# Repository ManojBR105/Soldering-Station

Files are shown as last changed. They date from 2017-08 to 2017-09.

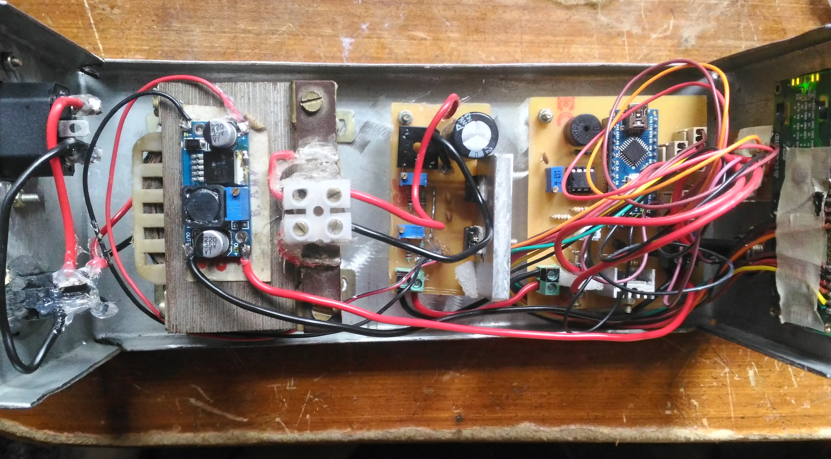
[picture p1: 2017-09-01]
FInished project/Top.jpg

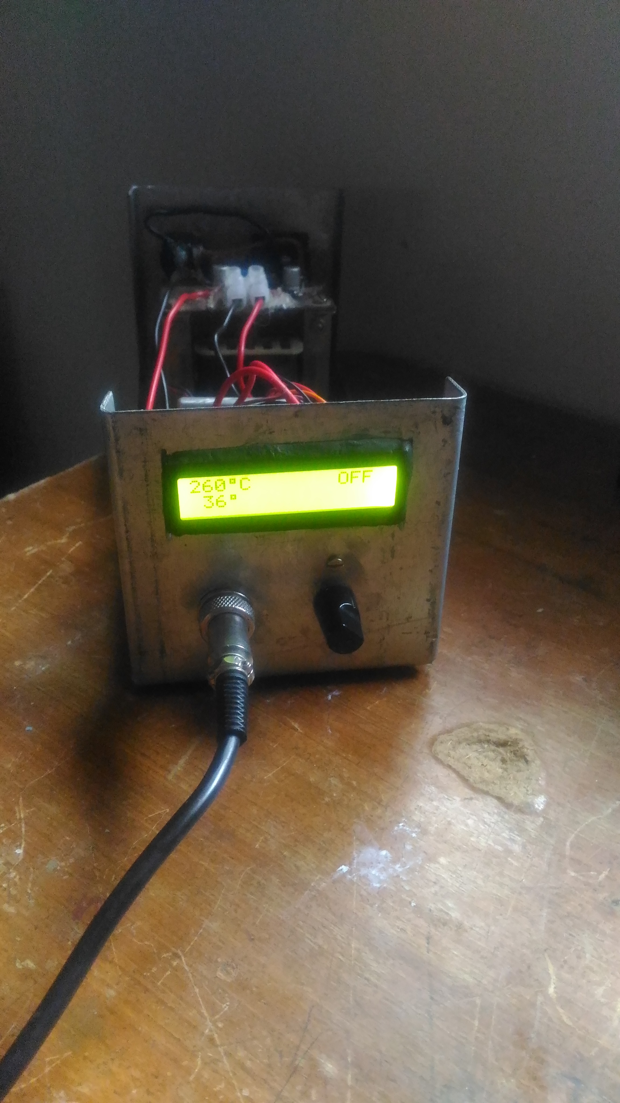
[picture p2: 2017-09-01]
FInished project/Front.jpg

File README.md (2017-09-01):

# Soldering-Station
Board and Schematics for Soldering station based on hakko 907 clone. 
Consider there is slight difference in schematic, the buzzer is connected to pin no.D13 of the arduino and the lcd pin connected to the D13th pin is connected to the D11th pin of the arduino. (please change this in the arduino code before uploading OR use the modified code in this repository).
In this layout LCD and Encoder are not on the PCB but are connected using Jumper Connectors which makes the assembling job easier when mounting this circuit into a Project case.
The eagle libraries that I have used for this schematic are also with this files copy them to your eagle library.
THANK YOU.

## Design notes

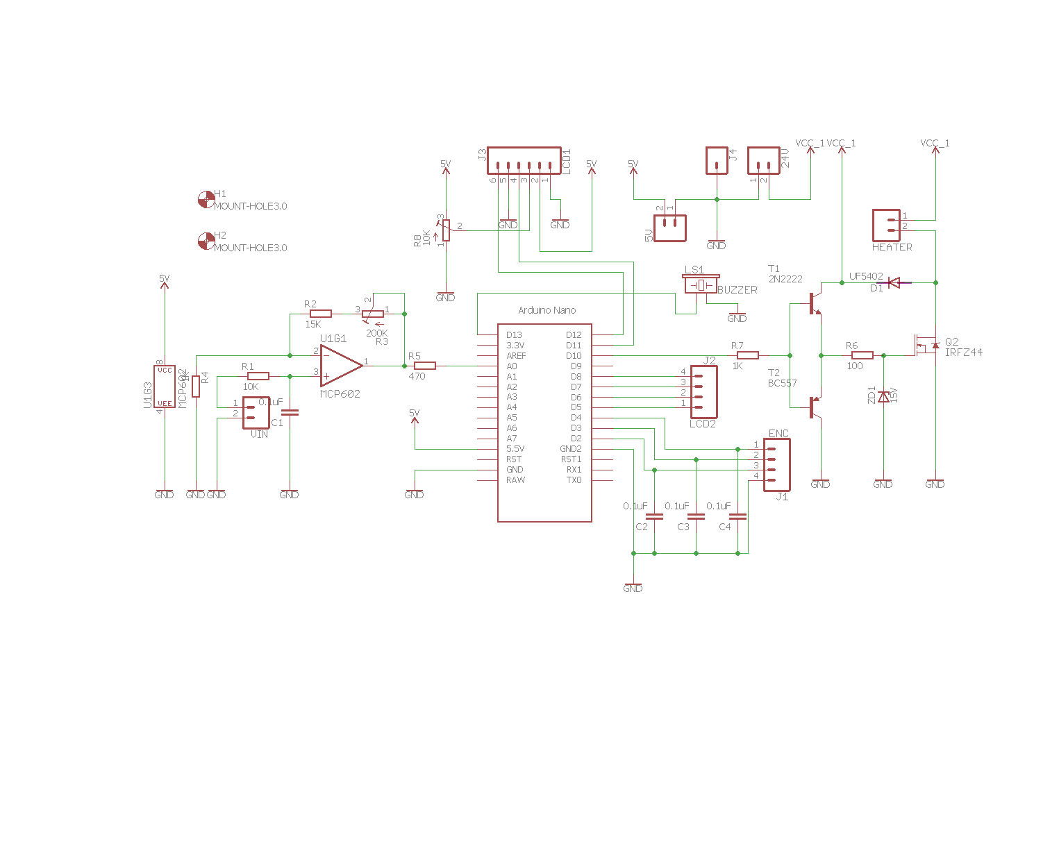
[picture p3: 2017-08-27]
EAGLE FILES/Soldering Station/Schematic.png

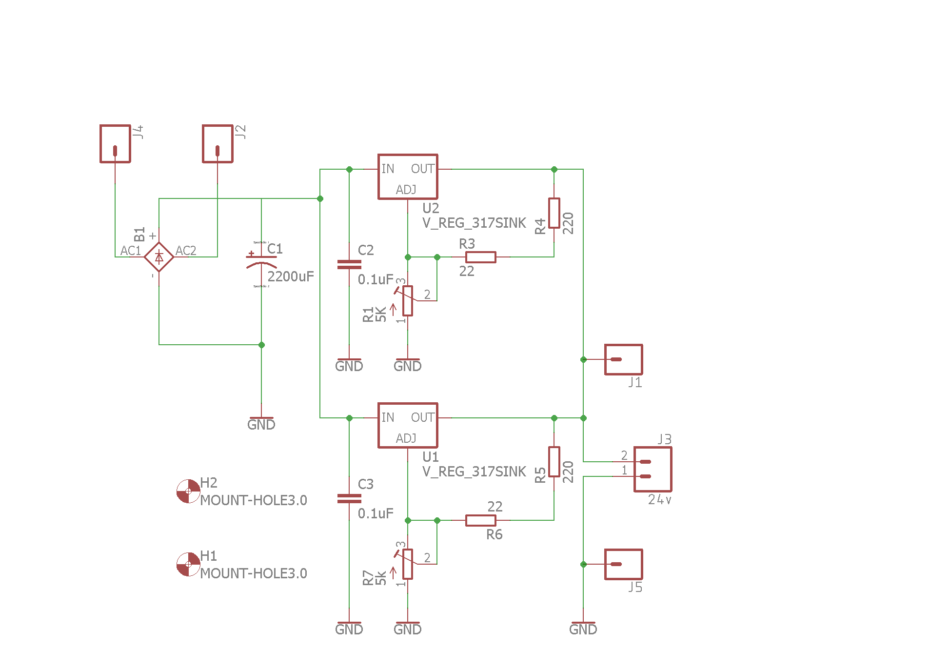
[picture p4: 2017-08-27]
EAGLE FILES/Power supply/Schematic.png

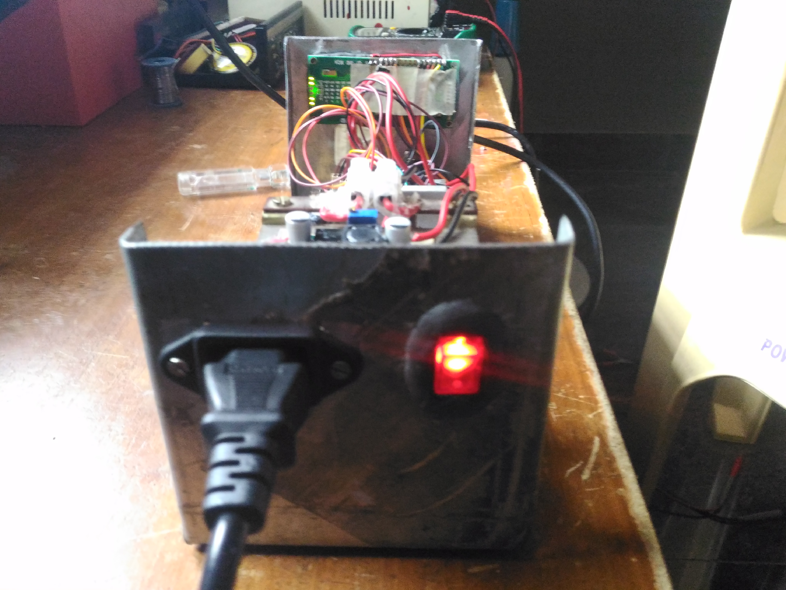
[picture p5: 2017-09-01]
FInished project/Back.jpg

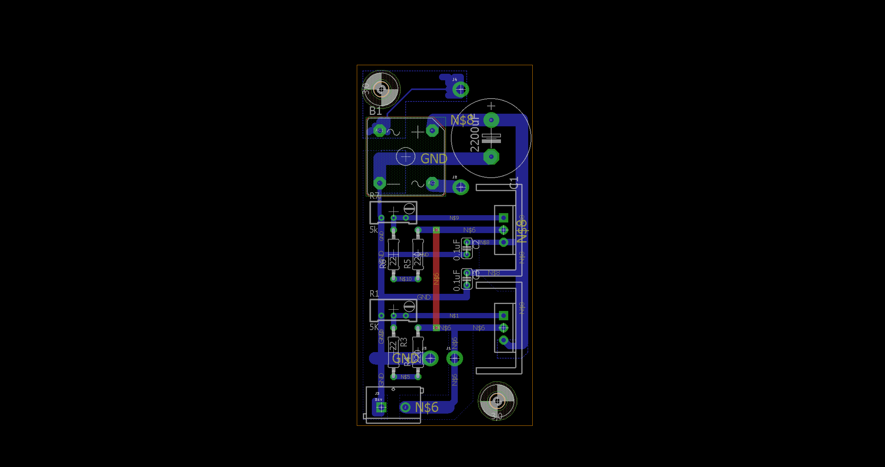
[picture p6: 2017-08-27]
EAGLE FILES/Power supply/Board.png

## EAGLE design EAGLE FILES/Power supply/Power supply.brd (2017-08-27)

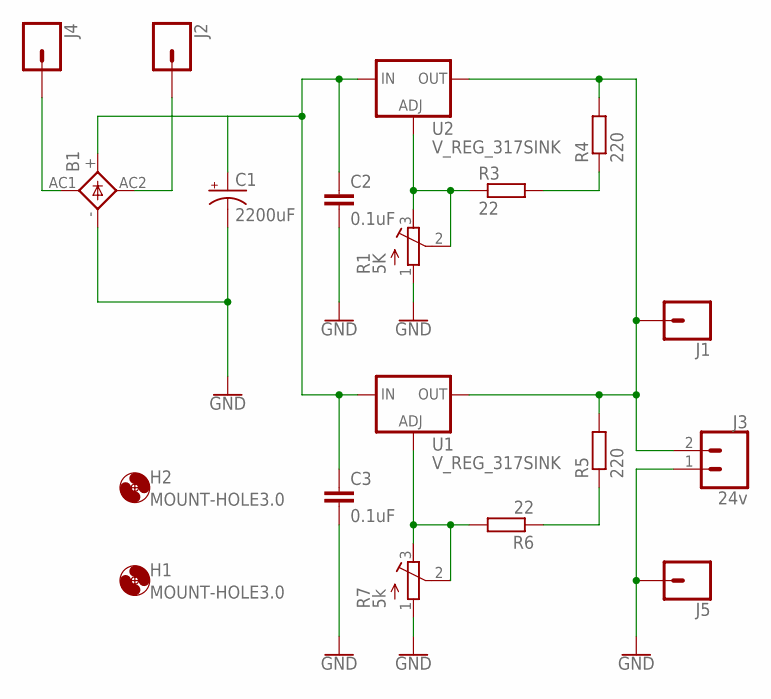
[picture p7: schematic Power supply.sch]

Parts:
B1: GBPC1
C1: 2200uF; E7,5-16
C2, C3: 0.1uF; C025-024X044
H1, H2: MOUNT-HOLE3.0; 3,0
J1, J2, J4, J5: CONN_01PTH_2MM; 1X01_2MM
J3: 24v; SCREWTERMINAL-5MM-2
R1: 5K; RTRIM64W
R3, R6: 22; 0207/10
R4, R5: 220; 0207/10
R7: 5k; RTRIM64W
U1, U2: V_REG_317SINK; TO220-ADJ

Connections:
GND: B1.-, C1.-, C2.2, C3.2, J3.1, J5.1, R1.1 (A), R7.1 (A)
unnamed: R1.2 (S), R1.3 (E), R3.1, U2.ADJ
unnamed: B1.AC1, J4.1
unnamed: B1.AC2, J2.1
unnamed: R3.2, R4.1
unnamed: J1.1, J3.2, R4.2, R5.2, U1.OUT, U2.OUT
unnamed: B1.+, C1.+, C2.1, C3.1, U1.IN, U2.IN
unnamed: R6.2, R7.2 (S), R7.3 (E), U1.ADJ
unnamed: R5.1, R6.1

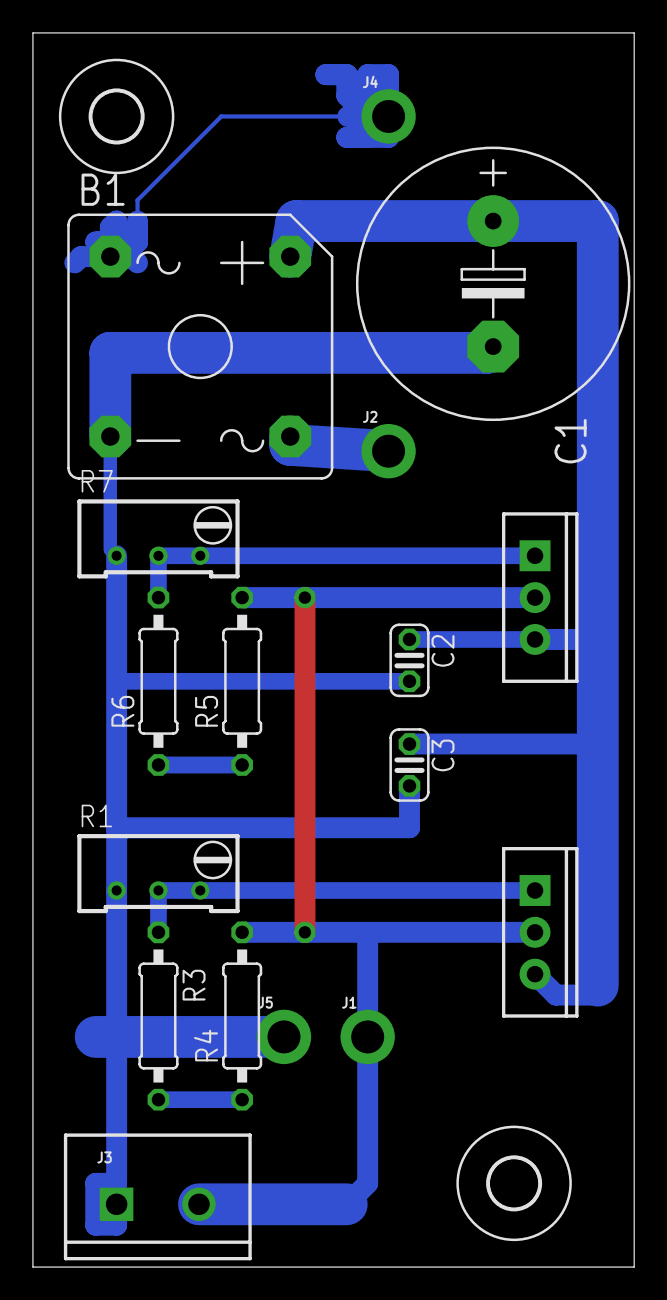
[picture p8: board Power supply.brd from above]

Board: 2 copper layers, 36.5 x 74.9 mm, 19 parts (0 on the bottom side), 9 nets.

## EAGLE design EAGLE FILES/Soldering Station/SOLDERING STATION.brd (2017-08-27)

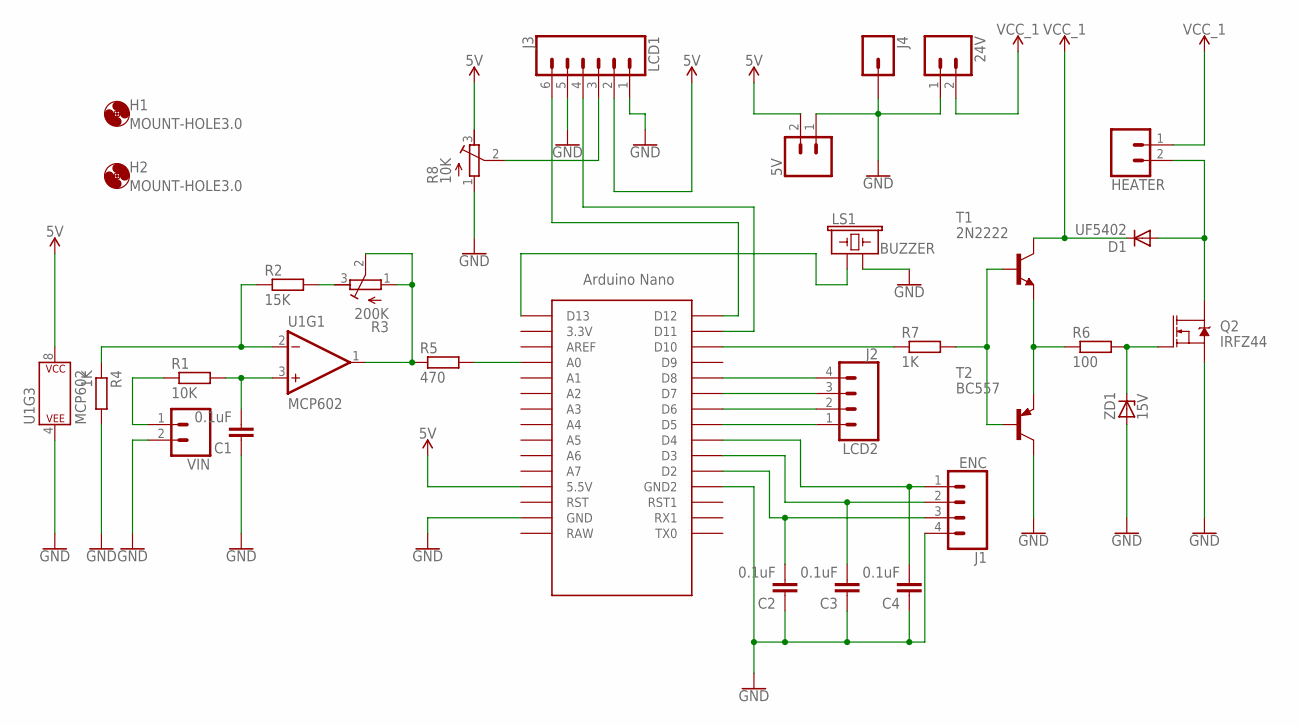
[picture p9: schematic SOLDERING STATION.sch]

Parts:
5V, 24V: CONN_025MM; SCREWTERMINAL-5MM-2
C1, C2, C3, C4: 0.1uF; C025-024X044
D1: UF5402; DO41-10
H1, H2: MOUNT-HOLE3.0; 3,0
HEATER: CONN_02PTH4; 1X02_XTRA_BIG
J1: ENC; 1X04_LONGPADS
J2: LCD2; 1X04_LONGPADS
J3: LCD1; 1X06_LONGPADS
J4: CONN_01PTH_2MM; 1X01_2MM
LS1: BUZZER; BUZZER-12MM-NS
Q2: IRFZ44; TO220V
R1: 10K; 0204/7
R2: 15K; 0204/7
R3: 200K; RTRIM64W
R4, R7: 1K; 0204/7
R5: 470; 0204/7
R6: 100; 0204/7
R8: 10K; RTRIM64W
T1: 2N2222; TO92-EBC-OVAL
T2: BC557; TO92
U1: MCP602; DIP08
U$1: NANO
VIN: CONN_02POLAR_LOCK; MOLEX-1X2_LOCK
ZD1: 15V; DO41Z10

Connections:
5V: 5V.2, J3.2, R8.3 (E), U1.8 (P$V+), U$1.5V (5.5V)
GND: 5V.1, 24V.1, C1.1, C2.1, C3.1, C4.1, J1.4, J3.1, J3.5, J4.1, LS1.- (2), Q2.3 (S), R4.2, R8.1 (A), T2.3 (C), U1.4 (P$V-), U$1.GND, U$1.GND1 (GND2), VIN.2, ZD1.A
unnamed: C1.2, R1.2, U1.3 (+IN)
unnamed: R2.1, R4.1, U1.2 (-IN)
unnamed: R1.1, VIN.1
unnamed: R2.2, R3.3 (E)
unnamed: R3.1 (A), R3.2 (S), R5.1, U1.1 (OUT)
unnamed: R5.2, U$1.A0
unnamed: R7.1, U$1.D10
unnamed: D1.A, HEATER.2, Q2.2 (D)
unnamed: C4.2, J1.1, U$1.D4
unnamed: R7.2, T1.B, T2.2 (B)
unnamed: R6.1, T1.E, T2.1 (E)
unnamed: Q2.1 (G), R6.2, ZD1.C
unnamed: C3.2, J1.2, U$1.D3
unnamed: C2.2, J1.3, U$1.D2
unnamed: J2.1, U$1.D5
unnamed: J2.2, U$1.D6
unnamed: J3.3, R8.2 (S)
unnamed: J2.3, U$1.D7
unnamed: J2.4, U$1.D8
unnamed: LS1.+ (1), U$1.D13
unnamed: J3.6, U$1.D12
unnamed: J3.4, U$1.D11
VCC_1: 24V.2, D1.C, HEATER.1, T1.C

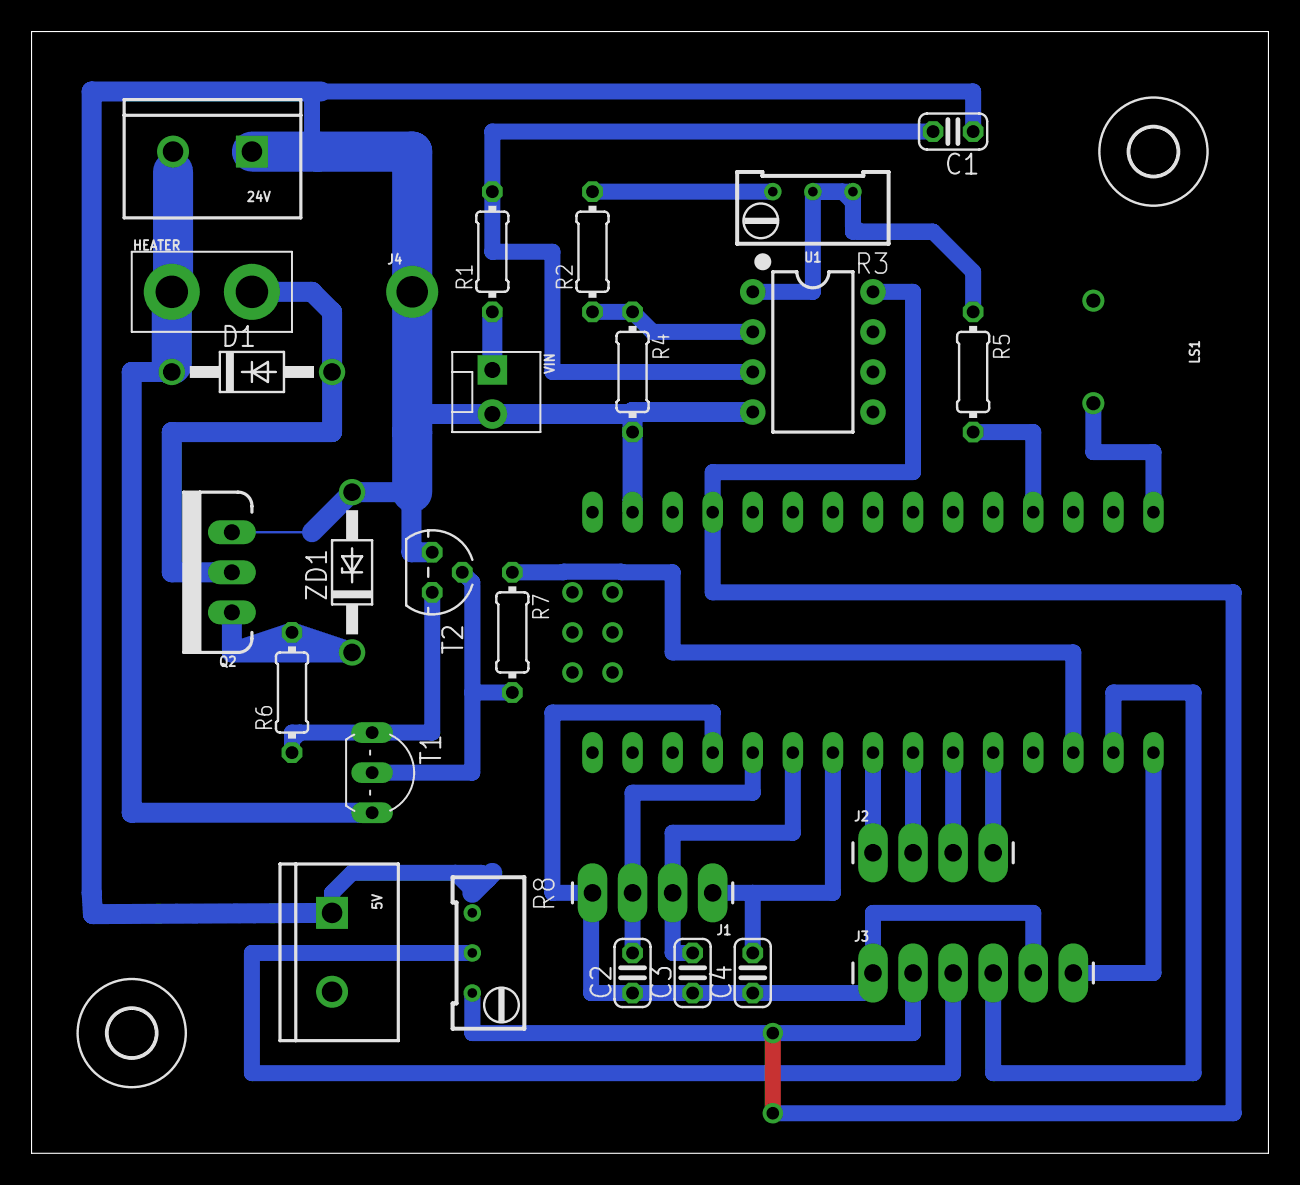
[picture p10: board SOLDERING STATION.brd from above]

Board: 2 copper layers, 78.4 x 71.1 mm, 30 parts (0 on the bottom side), 25 nets.

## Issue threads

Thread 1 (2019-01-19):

Soldering -Station / Modified.ino

giorgio-palma, 2019-01-19:
I've been trying to compile the sketch for a long time "
Modified.ino "(for display 1602) with the following arduino IDE version:
1.6.2
1.6.3
1.8.8 IDE
but the code gives me a compilation error.
You can help me??

giorgio-palma, 2019-01-25:
This is the error when compiling the "Modified.ino" code:
Arduino: 1.8.8 (Windows 8.1), Board: "Arduino Nano, ATmega328"

C:\Program Files (x86)\Arduino\arduino-builder -dump-prefs -logger=machine -hardware C:\Program Files (x86)\Arduino\hardware -hardware C:\Users\GIORGIOP\AppData\Local\Arduino15\packages -tools C:\Program Files (x86)\Arduino\tools-builder -tools C:\Program Files (x86)\Arduino\hardware\tools\avr -tools C:\Users\GIORGIOP\AppData\Local\Arduino15\packages -built-in-libraries C:\Program Files (x86)\Arduino\libraries -libraries C:\Users\GIORGIOP\Documents\Arduino\libraries -fqbn=arduino:avr:nano:cpu=atmega328 -ide-version=10808 -build-path C:\Users\GIORGIOP\AppData\Local\Temp\arduino_build_808351 -warnings=none -build-cache C:\Users\GIORGIOP\AppData\Local\Temp\arduino_cache_141 -prefs=build.warn_data_percentage=75 -prefs=runtime.tools.avrdude.path=C:\Users\GIORGIOP\AppData\Local\Arduino15\packages\arduino\tools\avrdude\6.0.1-arduino2 -prefs=runtime.tools.avrdude-6.0.1-arduino2.path=C:\Users\GIORGIOP\AppData\Local\Arduino15\packages\arduino\tools\avrdude\6.0.1-arduino2 -prefs=runtime.tools.avr-gcc.path=C:\Users\GIORGIOP\AppData\Local\Arduino15\packages\arduino\tools\avr-gcc\4.8.1-arduino2 -prefs=runtime.tools.avr-gcc-4.8.1-arduino2.path=C:\Users\GIORGIOP\AppData\Local\Arduino15\packages\arduino\tools\avr-gcc\4.8.1-arduino2 -verbose C:\Users\GIORGIOP\AppData\Local\Temp\arduino_modified_sketch_540121\sketch_jan25a.ino
C:\Program Files (x86)\Arduino\arduino-builder -compile -logger=machine -hardware C:\Program Files (x86)\Arduino\hardware -hardware C:\Users\GIORGIOP\AppData\Local\Arduino15\packages -tools C:\Program Files (x86)\Arduino\tools-builder -tools C:\Program Files (x86)\Arduino\hardware\tools\avr -tools C:\Users\GIORGIOP\AppData\Local\Arduino15\packages -built-in-libraries C:\Program Files (x86)\Arduino\libraries -libraries C:\Users\GIORGIOP\Documents\Arduino\libraries -fqbn=arduino:avr:nano:cpu=atmega328 -ide-version=10808 -build-path C:\Users\GIORGIOP\AppData\Local\Temp\arduino_build_808351 -warnings=none -build-cache C:\Users\GIORGIOP\AppData\Local\Temp\arduino_cache_141 -prefs=build.warn_data_percentage=75 -prefs=runtime.tools.avrdude.path=C:\Users\GIORGIOP\AppData\Local\Arduino15\packages\arduino\tools\avrdude\6.0.1-arduino2 -prefs=runtime.tools.avrdude-6.0.1-arduino2.path=C:\Users\GIORGIOP\AppData\Local\Arduino15\packages\arduino\tools\avrdude\6.0.1-arduino2 -prefs=runtime.tools.avr-gcc.path=C:\Users\GIORGIOP\AppData\Local\Arduino15\packages\arduino\tools\avr-gcc\4.8.1-arduino2 -prefs=runtime.tools.avr-gcc-4.8.1-arduino2.path=C:\Users\GIORGIOP\AppData\Local\Arduino15\packages\arduino\tools\avr-gcc\4.8.1-arduino2 -verbose C:\Users\GIORGIOP\AppData\Local\Temp\arduino_modified_sketch_540121\sketch_jan25a.ino
Using board 'nano' from platform in folder: C:\Users\GIORGIOP\AppData\Local\Arduino15\packages\arduino\hardware\avr\1.6.2
Using core 'arduino' from platform in folder: C:\Users\GIORGIOP\AppData\Local\Arduino15\packages\arduino\hardware\avr\1.6.2
WARNING: Category '' in library EEPROM is not valid. Setting to 'Uncategorized'
WARNING: Category '' in library SPI is not valid. Setting to 'Uncategorized'
WARNING: Category '' in library SoftwareSerial is not valid. Setting to 'Uncategorized'
WARNING: Category '' in library Wire is not valid. Setting to 'Uncategorized'
Warning: platform.txt from core 'Arduino AVR Boards' contains deprecated recipe.ar.pattern="{compiler.path}{compiler.ar.cmd}" {compiler.ar.flags} {compiler.ar.extra_flags} "{build.path}/{archive_file}" "{object_file}", automatically converted to recipe.ar.pattern="{compiler.path}{compiler.ar.cmd}" {compiler.ar.flags} {compiler.ar.extra_flags} "{archive_file_path}" "{object_file}". Consider upgrading this core.
Detecting libraries used...
"C:\\Users\\GIORGIOP\\AppData\\Local\\Arduino15\\packages\\arduino\\tools\\avr-gcc\\4.8.1-arduino2/bin/avr-g++" -c -g -Os -w -fno-exceptions -ffunction-sections -fdata-sections -fno-threadsafe-statics -w -x c++ -E -CC -mmcu=atmega328p -DF_CPU=16000000L -DARDUINO=10808 -DARDUINO_AVR_NANO -DARDUINO_ARCH_AVR "-IC:\\Users\\GIORGIOP\\AppData\\Local\\Arduino15\\packages\\arduino\\hardware\\avr\\1.6.2\\cores\\arduino" "-IC:\\Users\\GIORGIOP\\AppData\\Local\\Arduino15\\packages\\arduino\\hardware\\avr\\1.6.2\\variants\\eightanaloginputs" "C:\\Users\\GIORGIOP\\AppData\\Local\\Temp\\arduino_build_808351\\sketch\\sketch_jan25a.ino.cpp" -o nul
"C:\\Users\\GIORGIOP\\AppData\\Local\\Arduino15\\packages\\arduino\\tools\\avr-gcc\\4.8.1-arduino2/bin/avr-g++" -c -g -Os -w -fno-exceptions -ffunction-sections -fdata-sections -fno-threadsafe-statics -w -x c++ -E -CC -mmcu=atmega328p -DF_CPU=16000000L -DARDUINO=10808 -DARDUINO_AVR_NANO -DARDUINO_ARCH_AVR "-IC:\\Users\\GIORGIOP\\AppData\\Local\\Arduino15\\packages\\arduino\\hardware\\avr\\1.6.2\\cores\\arduino" "-IC:\\Users\\GIORGIOP\\AppData\\Local\\Arduino15\\packages\\arduino\\hardware\\avr\\1.6.2\\variants\\eightanaloginputs" "-IC:\\Program Files (x86)\\Arduino\\libraries\\LiquidCrystal\\src" "C:\\Users\\GIORGIOP\\AppData\\Local\\Temp\\arduino_build_808351\\sketch\\sketch_jan25a.ino.cpp" -o nul
"C:\\Users\\GIORGIOP\\AppData\\Local\\Arduino15\\packages\\arduino\\tools\\avr-gcc\\4.8.1-arduino2/bin/avr-g++" -c -g -Os -w -fno-exceptions -ffunction-sections -fdata-sections -fno-threadsafe-statics -w -x c++ -E -CC -mmcu=atmega328p -DF_CPU=16000000L -DARDUINO=10808 -DARDUINO_AVR_NANO -DARDUINO_ARCH_AVR "-IC:\\Users\\GIORGIOP\\AppData\\Local\\Arduino15\\packages\\arduino\\hardware\\avr\\1.6.2\\cores\\arduino" "-IC:\\Users\\GIORGIOP\\AppData\\Local\\Arduino15\\packages\\arduino\\hardware\\avr\\1.6.2\\variants\\eightanaloginputs" "-IC:\\Program Files (x86)\\Arduino\\libraries\\LiquidCrystal\\src" "-IC:\\Users\\GIORGIOP\\AppData\\Local\\Arduino15\\packages\\arduino\\hardware\\avr\\1.6.2\\libraries\\EEPROM" "C:\\Users\\GIORGIOP\\AppData\\Local\\Temp\\arduino_build_808351\\sketch\\sketch_jan25a.ino.cpp" -o nul
"C:\\Users\\GIORGIOP\\AppData\\Local\\Arduino15\\packages\\arduino\\tools\\avr-gcc\\4.8.1-arduino2/bin/avr-g++" -c -g -Os -w -fno-exceptions -ffunction-sections -fdata-sections -fno-threadsafe-statics -w -x c++ -E -CC -mmcu=atmega328p -DF_CPU=16000000L -DARDUINO=10808 -DARDUINO_AVR_NANO -DARDUINO_ARCH_AVR "-IC:\\Users\\GIORGIOP\\AppData\\Local\\Arduino15\\packages\\arduino\\hardware\\avr\\1.6.2\\cores\\arduino" "-IC:\\Users\\GIORGIOP\\AppData\\Local\\Arduino15\\packages\\arduino\\hardware\\avr\\1.6.2\\variants\\eightanaloginputs" "-IC:\\Program Files (x86)\\Arduino\\libraries\\LiquidCrystal\\src" "-IC:\\Users\\GIORGIOP\\AppData\\Local\\Arduino15\\packages\\arduino\\hardware\\avr\\1.6.2\\libraries\\EEPROM" "C:\\Program Files (x86)\\Arduino\\libraries\\LiquidCrystal\\src\\LiquidCrystal.cpp" -o nul
Generating function prototypes...
"C:\\Users\\GIORGIOP\\AppData\\Local\\Arduino15\\packages\\arduino\\tools\\avr-gcc\\4.8.1-arduino2/bin/avr-g++" -c -g -Os -w -fno-exceptions -ffunction-sections -fdata-sections -fno-threadsafe-statics -w -x c++ -E -CC -mmcu=atmega328p -DF_CPU=16000000L -DARDUINO=10808 -DARDUINO_AVR_NANO -DARDUINO_ARCH_AVR "-IC:\\Users\\GIORGIOP\\AppData\\Local\\Arduino15\\packages\\arduino\\hardware\\avr\\1.6.2\\cores\\arduino" "-IC:\\Users\\GIORGIOP\\AppData\\Local\\Arduino15\\packages\\arduino\\hardware\\avr\\1.6.2\\variants\\eightanaloginputs" "-IC:\\Program Files (x86)\\Arduino\\libraries\\LiquidCrystal\\src" "-IC:\\Users\\GIORGIOP\\AppData\\Local\\Arduino15\\packages\\arduino\\hardware\\avr\\1.6.2\\libraries\\EEPROM" "C:\\Users\\GIORGIOP\\AppData\\Local\\Temp\\arduino_build_808351\\sketch\\sketch_jan25a.ino.cpp" -o "C:\\Users\\GIORGIOP\\AppData\\Local\\Temp\\arduino_build_808351\\preproc\\ctags_target_for_gcc_minus_e.cpp"
"C:\\Program Files (x86)\\Arduino\\tools-builder\\ctags\\5.8-arduino11/ctags" -u --language-force=c++ -f - --c++-kinds=svpf --fields=KSTtzns --line-directives "C:\\Users\\GIORGIOP\\AppData\\Local\\Temp\\arduino_build_808351\\preproc\\ctags_target_for_gcc_minus_e.cpp"
Compiling sketch...
"C:\\Users\\GIORGIOP\\AppData\\Local\\Arduino15\\packages\\arduino\\tools\\avr-gcc\\4.8.1-arduino2/bin/avr-g++" -c -g -Os -w -fno-exceptions -ffunction-sections -fdata-sections -fno-threadsafe-statics -MMD -mmcu=atmega328p -DF_CPU=16000000L -DARDUINO=10808 -DARDUINO_AVR_NANO -DARDUINO_ARCH_AVR "-IC:\\Users\\GIORGIOP\\AppData\\Local\\Arduino15\\packages\\arduino\\hardware\\avr\\1.6.2\\cores\\arduino" "-IC:\\Users\\GIORGIOP\\AppData\\Local\\Arduino15\\packages\\arduino\\hardware\\avr\\1.6.2\\variants\\eightanaloginputs" "-IC:\\Program Files (x86)\\Arduino\\libraries\\LiquidCrystal\\src" "-IC:\\Users\\GIORGIOP\\AppData\\Local\\Arduino15\\packages\\arduino\\hardware\\avr\\1.6.2\\libraries\\EEPROM" "C:\\Users\\GIORGIOP\\AppData\\Local\\Temp\\arduino_build_808351\\sketch\\sketch_jan25a.ino.cpp" -o "C:\\Users\\GIORGIOP\\AppData\\Local\\Temp\\arduino_build_808351\\sketch\\sketch_jan25a.ino.cpp.o"
C:\Users\GIORGIOP\AppData\Local\Temp\arduino_modified_sketch_540121\sketch_jan25a.ino: In member function 'void DSPL::init()':

sketch_jan25a:553:36: error: invalid conversion from 'const byte* {aka const unsigned char*}' to 'uint8_t* {aka unsigned char*}' [-fpermissive]

   LiquidCrystal::createChar(1, cent);

                                    ^

In file included from C:\Users\GIORGIOP\AppData\Local\Temp\arduino_modified_sketch_540121\sketch_jan25a.ino:1:0:

C:\Program Files (x86)\Arduino\libraries\LiquidCrystal\src/LiquidCrystal.h:81:8: error:   initializing argument 2 of 'void LiquidCrystal::createChar(uint8_t, uint8_t*)' [-fpermissive]

   void createChar(uint8_t, uint8_t[]);

        ^

Using library LiquidCrystal at version 1.0.7 in folder: C:\Program Files (x86)\Arduino\libraries\LiquidCrystal
Using library EEPROM at version 2.0 in folder: C:\Users\GIORGIOP\AppData\Local\Arduino15\packages\arduino\hardware\avr\1.6.2\libraries\EEPROM
exit status 1
invalid conversion from 'const byte* {aka const unsigned char*}' to 'uint8_t* {aka unsigned char*}' [-fpermissive]

DeshmukhMalhar, 2019-01-26:
try changing
` const byte cent[8] `
to
` const uint8_t cent[8] `

giorgio-palma, 2019-01-26:
thank you so much now compile it out perfectly.
I had to change
"const byte cent[8]"
to
"uint8_t cent[8]"

Closed 2020-12-08.

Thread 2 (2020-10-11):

Current temp never changes

zhuhualong, 2020-10-11:
Hey Manoj,

I used your files (PCB and code) to make this sweet project.  Everything turned out great, but one little problem...  The Iron temp never changes from 25C.  I have tried two different irons and get the same.  If I click ON, it displays, "HEATING" and the percentage changes from 0% to 100% almost immediately and the it heats to almost 520C by my thermometer.

I am using your PCB.  I didn't have it printed, I made it myself.  The iron reads 50 Ohms when cold.  I have double checked all of the connections and the code "modified.ino" loads fine, no mods.

Do you have any suggestions on where to look?

I did notice one thing and it might mean nothing, when there is no iron connected, the temp reads at about 348C.

Thanks,
Michael

zhuhualong, 2020-10-12:
I did notice one thing while doing some testing with the multimeter, when I have the unit on, and connect the leads to the sensor pins, the temperature on the LCD displays correctly.  What do you think might be the problem?
I've double checked all of the solder joints for this part of the circuit and even swapped the MCP602 chip just to rule out a faulty IC.

Thanks
Michael

ManojBR105, 2020-12-08:
Hey Michael,
Sorry for replying late, I don't get notifications if you comment here. You can mail me at MakerBR555@gmail.com if you have any doubts.
I suggest you to test 2 things.
1. There is one red wire in the pcb, which is supposed to be a jumper wire that you have to solder from top externally. Make sure you did that.
2. Verify that your Soldering Iron has a thermocouple not thermistor as the temperature sensor.

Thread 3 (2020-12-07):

mistake in pcb file

samsam1202, 2020-12-07:
hi dear Manoj

I tried to build your project.

https://github.com/ManojBR105/Soldering-Station

I think there was a mistake in your eagle PCB board.

the 5-volt positive input in the PCB is grounded and did not connect to anything.

please check the screenshot bellow:

https://imgur.com/a/DPOdkQ3

can you explain what can I do.

thanks

ManojBR105, 2020-12-08:
Click on Ratnest icon it should fill the planes and you will be able to see connections.

samsam1202, 2020-12-09:
> Click on Ratnest icon it should fill the planes and you will be able to see connections.
done. thanks

samsam1202, 2020-12-09:
> Click on Ratnest icon it should fill the planes and you will be able to see connections.

done . thanks

Closed 2020-12-09.

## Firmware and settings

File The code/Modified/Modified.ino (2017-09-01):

#include <LiquidCrystal.h>
#include <EEPROM.h>


// The LCD 0802 parallel interface
const byte LCD_RS_PIN     = 11;
const byte LCD_E_PIN      = 12;
const byte LCD_DB4_PIN    = 5;
const byte LCD_DB5_PIN    = 6;
const byte LCD_DB6_PIN    = 7;
const byte LCD_DB7_PIN    = 8;

// Rotary encoder interface
const byte R_MAIN_PIN = 2;                      // Rotary Encoder main pin (right)
const byte R_SECD_PIN = 4;                      // Rotary Encoder second pin (left)
const byte R_BUTN_PIN = 3;                      // Rotary Encoder push button pin

const byte probePIN  = A0;                      // Thermometer pin from soldering iron
const byte heaterPIN = 10;                      // The soldering iron heater pin
const byte buzzerPIN = 13;                      // The simple buzzer to make a noise

const uint16_t temp_minC = 180;                 // Minimum temperature in degrees of celsius
const uint16_t temp_maxC = 400;                 // Maximum temperature in degrees of celsius
const uint16_t temp_minF = (temp_minC *9 + 32*5 + 2)/5;
const uint16_t temp_maxF = (temp_maxC *9 + 32*5 + 2)/5;
const uint16_t temp_tip[3] = {200, 300, 400};

// The variables for Timer1 operations
volatile uint16_t  tmr1_count;                  // The count to calculate the temperature check period
volatile bool      iron_off;                    // Whether the IRON is switched off to check the temperature
const uint32_t     check_period = 100;          // The IRON temperature check period, ms

//------------------------------------------ Configuration data ------------------------------------------------
/* Config record in the EEPROM has the following format:
  uint32_t ID                           each time increment by 1
  struct cfg                            config data, 8 bytes
  byte CRC                              the checksum
*/
struct cfg {
  uint32_t calibration;                         // The temperature calibration data for soldering IRON. (3 reference points: 200, 300, 400 Centegrees)
  uint16_t temp;                                // The preset temperature of the IRON in the internal units
  byte     off_timeout;                         // The Automatic switch-off timeout in minutes [0 - 30]
  bool     celsius;                             // Temperature units: true - Celsius, false - Farenheit
};

class CONFIG {
  public:
    CONFIG() {
      can_write     = false;
      buffRecords   = 0;
      rAddr = wAddr = 0;
      eLength       = 0;
      nextRecID     = 0;
      byte rs = sizeof(struct cfg) + 5;               // The total config record size
      // Select appropriate record size; The record size should be power of 2, i.e. 8, 16, 32, 64, ... bytes
      for (record_size = 8; record_size < rs; record_size <<= 1);
    }
    void init();
    bool load(void);
    void getConfig(struct cfg &Cfg);                  // Copy config structure from this class
    void updateConfig(struct cfg &Cfg);               // Copy updated config into this class
    bool save(void);                                  // Save current config copy to the EEPROM
    bool saveConfig(struct cfg &Cfg);                 // write updated config into the EEPROM
    void clearAll(void);                              // Clean all EEPROM

  protected:
    struct   cfg Config;

  private:
    bool     readRecord(uint16_t addr, uint32_t &recID);
    bool     can_write;                               // The flag indicates that data can be saved
    byte     buffRecords;                             // Number of the records in the outpt buffer
    uint16_t rAddr;                                   // Address of thecorrect record in EEPROM to be read
    uint16_t wAddr;                                   // Address in the EEPROM to start write new record
    uint16_t eLength;                                 // Length of the EEPROM, depends on arduino model
    uint32_t nextRecID;                               // next record ID
    byte     record_size;                             // The size of one record in bytes
};

 // Read the records until the last one, point wAddr (write address) after the last record
void CONFIG::init(void) {
  eLength = EEPROM.length();
  uint32_t recID;
  uint32_t minRecID = 0xffffffff;
  uint16_t minRecAddr = 0;
  uint32_t maxRecID = 0;
  uint16_t maxRecAddr = 0;
  byte records = 0;

  nextRecID = 0;

  // read all the records in the EEPROM find min and max record ID
  for (uint16_t addr = 0; addr < eLength; addr += record_size) {
    if (readRecord(addr, recID)) {
      ++records;
      if (minRecID > recID) {
        minRecID = recID;
        minRecAddr = addr;
      }
      if (maxRecID < recID) {
        maxRecID = recID;
        maxRecAddr = addr;
      }
    } else {
      break;
    }
  }

  if (records == 0) {
    wAddr = rAddr = 0;
    can_write = true;
    return;
  }

  rAddr = maxRecAddr;
  if (records < (eLength / record_size)) {            // The EEPROM is not full
    wAddr = rAddr + record_size;
    if (wAddr > eLength) wAddr = 0;
  } else {
    wAddr = minRecAddr;
  }
  can_write = true;
}

void CONFIG::getConfig(struct cfg &Cfg) {
  memcpy(&Cfg, &Config, sizeof(struct cfg));
}

void CONFIG::updateConfig(struct cfg &Cfg) {
  memcpy(&Config, &Cfg, sizeof(struct cfg));
}

bool CONFIG::saveConfig(struct cfg &Cfg) {
  updateConfig(Cfg);
  return save();                                      // Save new data into the EEPROM
}

bool CONFIG::save(void) {
  if (!can_write) return can_write;
  if (nextRecID == 0) nextRecID = 1;

  uint16_t startWrite = wAddr;
  uint32_t nxt = nextRecID;
  byte summ = 0;
  for (byte i = 0; i < 4; ++i) {
    EEPROM.write(startWrite++, nxt & 0xff);
    summ <<=2; summ += nxt;
    nxt >>= 8;
  }
  byte* p = (byte *)&Config;
  for (byte i = 0; i < sizeof(struct cfg); ++i) {
    summ <<= 2; summ += p[i];
    EEPROM.write(startWrite++, p[i]);
  }
  summ ++;                                            // To avoid empty records
  EEPROM.write(wAddr+record_size-1, summ);

  rAddr = wAddr;
  wAddr += record_size;
  if (wAddr > EEPROM.length()) wAddr = 0;
  nextRecID ++;                                       // Get ready to write next record
  return true;
}

bool CONFIG::load(void) {
  bool is_valid = readRecord(rAddr, nextRecID);
  nextRecID ++;
  return is_valid;
}

bool CONFIG::readRecord(uint16_t addr, uint32_t &recID) {
  byte Buff[record_size];

  for (byte i = 0; i < record_size; ++i) 
    Buff[i] = EEPROM.read(addr+i);
  
  byte summ = 0;
  for (byte i = 0; i < sizeof(struct cfg) + 4; ++i) {

    summ <<= 2; summ += Buff[i];
  }
  summ ++;                                            // To avoid empty fields
  if (summ == Buff[record_size-1]) {                  // Checksumm is correct
    uint32_t ts = 0;
    for (char i = 3; i >= 0; --i) {
      ts <<= 8;
      ts |= Buff[byte(i)];
    }
    recID = ts;
    memcpy(&Config, &Buff[4], sizeof(struct cfg));
    return true;
  }
  return false;
}

void CONFIG::clearAll(void) {
  for (int i = 0; i < eLength; ++i)
    EEPROM.write(i, 0);
  init();
  load();
}

//------------------------------------------ class IRON CONFIG -------------------------------------------------
class IRON_CFG : public CONFIG {
  public:
    IRON_CFG()                                  { current_tip = 0; t_tip[0] = t_tip[1] = t_tip[2] = 0; is_calibrated = false; }
    void     init(void);
    bool     isCelsius(void)                    { return Config.celsius; }
    bool     isCold(uint16_t temp);             // Whether the IRON is temperature is low
    uint16_t tempPresetHuman(void);             // The preset Temperature in the human readable units
    uint16_t tempPreset(void)                   { return Config.temp; }
    uint16_t human2temp(uint16_t temp);         // Translate the human readable temperature into internal value
    uint16_t tempHuman(uint16_t temp);          // Thanslate temperature from internal units to the human readable value (Celsius or Farenheit)
    byte     selectTip(byte index);             // Select new tip, return selected tip index
    byte     getOffTimeout(void)                { return Config.off_timeout; }
    bool     getTempUnits(void)                 { return Config.celsius; }
    bool     savePresetTempHuman(uint16_t temp);// Save preset temperature in the human readable units
    bool     savePresetTemp(uint16_t temp);     // Save preset temperature in the internal units (convert it to the human readable units)
    void     saveConfig(byte off, bool cels);   // Save global configuration parameters
    void     getCalibrationData(uint16_t& t_min, uint16_t& t_mid, uint16_t& t_max);
    void     saveCalibrationData(uint16_t t_min, uint16_t t_mid, uint16_t t_max);
    void     setDefaults(bool Write = false);   // Set default parameter values if failed to load data from EEPROM
  private:
    byte     current_tip;                       // The current tip index
    bool     is_calibrated;                     // whether the tip has calibrated data
    // t_tip[] - array of internal sensor readings of the current tip at reference temperatures,
    // defined in temp_tip[] global array
    uint16_t t_tip[3];
    const uint16_t def_tip[3] = {420, 660, 885};// Default values of internal sensor readings at reference temperatures
    const uint16_t def_set = 513;               // Default preset temperature in internal units
    const uint16_t ambient_temp  = 18;         // Ambient temperatire in the internal units
    const uint16_t ambient_tempC = 25;          // Ambient temperature in Celsius
};

void IRON_CFG::init(void) {
  CONFIG::init();
  if (!CONFIG::load()) setDefaults();           // If failed to load the data from EEPROM, initialize the config data with default values
  uint32_t   cd = Config.calibration;
  t_tip[0] = cd & 0x3FF; cd >>= 10;             // 10 bits per calibration parameter, because the ADC readings are 10 bits
  t_tip[1] = cd & 0x3FF; cd >>= 10;
  t_tip[2] = cd & 0x3FF;
  // Check the tip calibration is correct
  if ((t_tip[0] >= t_tip[1]) || (t_tip[1] >= t_tip[2])) {
    setDefaults();
    for (byte i = 0; i < 3; ++i)
      t_tip[i] = def_tip[i];
  }
}

bool IRON_CFG::isCold(uint16_t temp) {
  return (temp < t_tip[0]) && (map(temp, ambient_temp, t_tip[0], ambient_tempC, temp_tip[0]) < 32);
}

uint16_t IRON_CFG::tempPresetHuman(void) {
  return tempHuman(Config.temp);
}

uint16_t IRON_CFG::human2temp(uint16_t t) {     // Translate the human readable temperature into internal value
  uint16_t temp = t;
  if (!Config.celsius)
    temp = map(temp, temp_minF, temp_maxF, temp_minC, temp_maxC);
  if (t < temp_minC) t = temp_minC;
  if (t > temp_maxC) t = temp_maxC;
  if (t >= temp_tip[1])
    temp = map(t+1, temp_tip[1], temp_tip[2], t_tip[1], t_tip[2]);
  else
    temp = map(t+1, temp_tip[0], temp_tip[1], t_tip[0], t_tip[1]);
 
  for (byte i = 0; i < 10; ++i) {
    uint16_t tH = tempHuman(temp);
    if (tH <= t) break;
    --temp;
  }
  return temp;
}

// Thanslate temperature from internal units to the human readable value (Celsius or Farenheit)
uint16_t IRON_CFG::tempHuman(uint16_t temp) {
  uint16_t tempH = 0;
  if (temp < ambient_temp) {
    tempH = ambient_tempC;
  } else if (temp < t_tip[0]) {
    tempH = map(temp, ambient_temp, t_tip[0], ambient_tempC, temp_tip[0]);
  } else if (temp >= t_tip[1]) {
    tempH = map(temp, t_tip[1], t_tip[2], temp_tip[1], temp_tip[2]);
  } else {
    tempH = map(temp, t_tip[0], t_tip[1], temp_tip[0], temp_tip[1]);
  }
  if (!Config.celsius)
    tempH = map(tempH, temp_minC, temp_maxC, temp_minF, temp_maxF);
  return tempH;
}

bool IRON_CFG::savePresetTempHuman(uint16_t temp) {
  Config.temp = human2temp(temp);
  return CONFIG::save();
}

bool IRON_CFG::savePresetTemp(uint16_t temp) {
  Config.temp = temp;
  return CONFIG::save();
}

void IRON_CFG::saveConfig(byte off, bool cels) {
  if (off > 30) off = 0;
  Config.off_timeout = off;
  Config.celsius = cels;
  CONFIG::save();                               // Save new data into the EEPROM
}

void IRON_CFG::getCalibrationData(uint16_t& t_min, uint16_t& t_mid, uint16_t& t_max) {
  t_min = t_tip[0];
  t_mid = t_tip[1];
  t_max = t_tip[2];
}

void IRON_CFG::saveCalibrationData(uint16_t t_min, uint16_t t_mid, uint16_t t_max) {
  uint32_t cd = t_max & 0x3FF; cd <<= 10;       // Pack tip calibration data in one 32-bit word: 10-bits per value
  cd |= t_mid & 0x3FF; cd <<= 10;
  cd |= t_min;

  Config.calibration = cd;
  t_tip[0] = t_min;
  t_tip[2] = t_mid;
  t_tip[2] = t_max;
}

void IRON_CFG::setDefaults(bool Write) {
  uint32_t c = def_tip[2] & 0x3FF; c <<= 10;
  c |= def_tip[1] & 0x3FF;         c <<= 10;
  c |= def_tip[0] & 0x3FF;
  Config.calibration = c;
  Config.temp        = def_set;
  Config.off_timeout = 0;                       // Default autometic switch-off timeout (disabled)
  Config.celsius     = true;                    // Default use celsius
  if (Write) {
    CONFIG::clearAll();
    CONFIG::save();
  }
}


//------------------------------------------ class BUZZER ------------------------------------------------------
class BUZZER {
  public:
    BUZZER(byte buzzerP)  { buzzer_pin = buzzerP; }
    void init(void);
    void shortBeep(void)  { tone(buzzerPIN, 3520, 160); }
    void lowBeep(void)    { tone(buzzerPIN,  880, 160); }
    void doubleBeep(void) { tone(buzzerPIN, 3520, 160); delay(300); tone(buzzerPIN, 3520, 160); }
    void failedBeep(void) { tone(buzzerPIN, 3520, 160); delay(170);
                            tone(buzzerPIN,  880, 250); delay(260);
                            tone(buzzerPIN, 3520, 160);
                          }
  private:
    byte buzzer_pin;
};

void BUZZER::init(void) {
  pinMode(buzzer_pin, OUTPUT);
  noTone(buzzer_pin);
}

//------------------------------------------ class BUTTON ------------------------------------------------------
class BUTTON {
  public:
    BUTTON(byte ButtonPIN, unsigned int timeout_ms = 3000) {
      pt = tickTime = 0;
      buttonPIN = ButtonPIN;
      overPress = timeout_ms;
    }
    void init(void) { pinMode(buttonPIN, INPUT_PULLUP); }
    void setTimeout(uint16_t timeout_ms = 3000) { overPress = timeout_ms; }
    byte intButtonStatus(void) { byte m = mode; mode = 0; return m; }
    void cnangeINTR(void);
    byte buttonCheck(void);
    bool buttonTick(void);
  private:
    volatile byte     mode;                     // The button mode: 0 - not pressed, 1 - pressed, 2 - long pressed
    uint16_t          overPress;                // Maxumum time in ms the button can be pressed
    volatile uint32_t pt;                       // Time in ms when the button was pressed (press time)
    uint32_t          tickTime;                 // The time in ms when the button Tick was set
    byte              buttonPIN;                // The pin number connected to the button
    const uint16_t    tickTimeout = 200;        // Period of button tick, while tha button is pressed 
    const uint16_t    shortPress = 900;         // If the button was pressed less that this timeout, we assume the short button press
};

void BUTTON::cnangeINTR(void) {                 // Interrupt function, called when the button status changed
  
  bool keyUp = digitalRead(buttonPIN);
  unsigned long now_t = millis();
  if (!keyUp) {                                 // The button has been pressed
    if ((pt == 0) || (now_t - pt > overPress)) pt = now_t; 
  } else {
    if (pt > 0) {
      if ((now_t - pt) < shortPress) mode = 1;  // short press
        else mode = 2;                          // long press
      pt = 0;
    }
  }
}

byte BUTTON::buttonCheck(void) {                // Check the button state, called each time in the main loop

  mode = 0;
  bool keyUp = digitalRead(buttonPIN);          // Read the current state of the button
  uint32_t now_t = millis();
  if (!keyUp) {                                 // The button is pressed
    if ((pt == 0) || (now_t - pt > overPress)) pt = now_t;
  } else {
    if (pt == 0) return 0;
    if ((now_t - pt) > shortPress)              // Long press
      mode = 2;
    else
      mode = 1;
    pt = 0;
  } 
  return mode;
}

bool BUTTON::buttonTick(void) {                 // When the button pressed for a while, generate periodical ticks

  bool keyUp = digitalRead(buttonPIN);          // Read the current state of the button
  uint32_t now_t = millis();
  if (!keyUp && (now_t - pt > shortPress)) {    // The button have been pressed for a while
    if (now_t - tickTime > tickTimeout) {
       tickTime = now_t;
       return (pt != 0);
    }
  } else {
    if (pt == 0) return false;
    tickTime = 0;
  } 
  return false;
}

//------------------------------------------ class ENCODER ------------------------------------------------------
class ENCODER {
  public:
    ENCODER(byte aPIN, byte bPIN, int16_t initPos = 0) {
      pt = 0; mPIN = aPIN; sPIN = bPIN; pos = initPos;
      min_pos = -32767; max_pos = 32766; channelB = false; increment = 1;
      changed = 0;
      is_looped = false;
    }
    void init(void) {
      pinMode(mPIN, INPUT_PULLUP);
      pinMode(sPIN, INPUT_PULLUP);
    }
    void    set_increment(byte inc)             { increment = inc; }
    byte    get_increment(void)                 { return increment; }
    int16_t read(void)                          { return pos; }
    void    reset(int16_t initPos, int16_t low, int16_t upp, byte inc = 1, byte fast_inc = 0, bool looped = false);
    bool    write(int16_t initPos);
    void    cnangeINTR(void);
  private:
    int32_t           min_pos, max_pos;
    volatile uint32_t pt;                       // Time in ms when the encoder was rotaded
    volatile uint32_t changed;                  // Time in ms when the value was changed
    volatile bool     channelB;
    volatile int16_t  pos;                      // Encoder current position
    byte              mPIN, sPIN;               // The pin numbers connected to the main channel and to the socondary channel
    bool              is_looped;                // Whether the encoder is looped
    byte              increment;                // The value to add or substract for each encoder tick
    byte              fast_increment;           // The value to change encoder when in runs quickly
    const uint16_t    fast_timeout = 300;       // Time in ms to change encodeq quickly
    const uint16_t    overPress = 1000;
};

bool ENCODER::write(int16_t initPos) {
  if ((initPos >= min_pos) && (initPos <= max_pos)) {
    pos = initPos;
    return true;
  }
  return false;
}

void ENCODER::reset(int16_t initPos, int16_t low, int16_t upp, byte inc, byte fast_inc, bool looped) {
  min_pos = low; max_pos = upp;
  if (!write(initPos)) initPos = min_pos;
  increment = fast_increment = inc;
  if (fast_inc > increment) fast_increment = fast_inc;
  is_looped = looped;
}

void ENCODER::cnangeINTR(void) {                // Interrupt function, called when the channel A of encoder changed
  
  bool rUp = digitalRead(mPIN);
  unsigned long now_t = millis();
  if (!rUp) {                                   // The channel A has been "pressed"
    if ((pt == 0) || (now_t - pt > overPress)) {
      pt = now_t;
      channelB = digitalRead(sPIN);
    }
  } else {
    if (pt > 0) {
      byte inc = increment;
      if ((now_t - pt) < overPress) {
        if ((now_t - changed) < fast_timeout) inc = fast_increment;
        changed = now_t;
        if (channelB) pos -= inc; else pos += inc;
        if (pos > max_pos) { 
          if (is_looped)
            pos = min_pos;
          else 
            pos = max_pos;
        }
        if (pos < min_pos) {
          if (is_looped)
            pos = max_pos;
          else
            pos = min_pos;
        }
      }
      pt = 0; 
    }
  }
}
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
void loop() {
  static int16_t old_pos = rotEncoder.read();
  iron.checkIron();                             // Periodically check that the IRON works correctrly

  bool iron_on = iron.isOn();
  if ((pCurrentScreen == &wrkScr) && !iron_on) {  // the soldering iron failed
    pCurrentScreen = &errScr;
    pCurrentScreen->init();
  }

  SCREEN* nxt = pCurrentScreen->returnToMain();
  if (nxt != pCurrentScreen) {                  // return to the main screen by timeout
    pCurrentScreen = nxt;
    pCurrentScreen->init();
  }

  byte bStatus = rotButton.intButtonStatus();
  switch (bStatus) {
    case 2:                                     // long press;
      nxt = pCurrentScreen->menu_long();
      if (nxt != pCurrentScreen) {
        pCurrentScreen = nxt;
        pCurrentScreen->init();
      } else {
        if (pCurrentScreen->isSetup())
         pCurrentScreen->resetTimeout();
      }
      break;
    case 1:                                     // short press
      nxt = pCurrentScreen->menu();
      if (nxt != pCurrentScreen) {
        pCurrentScreen = nxt;
        pCurrentScreen->init();
      } else {
        if (pCurrentScreen->isSetup())
         pCurrentScreen->resetTimeout();
      }
      break;
    case 0:                                     // Not pressed
    default:
      break;
  }

  int16_t pos = rotEncoder.read();
  if (old_pos != pos) {
    pCurrentScreen->rotaryValue(pos);
    old_pos = pos;
    if (pCurrentScreen->isSetup())
     pCurrentScreen->resetTimeout();
  }

  pCurrentScreen->show();
}

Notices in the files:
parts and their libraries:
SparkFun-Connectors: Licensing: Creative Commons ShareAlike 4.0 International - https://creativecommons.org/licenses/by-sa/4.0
